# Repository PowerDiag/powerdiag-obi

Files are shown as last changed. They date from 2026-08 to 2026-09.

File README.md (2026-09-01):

# PowerDiag OBI — Interface Board

**PowerDiag OBI** is a dedicated hardware interface board (OBI V1.1, 2026.09.01) built around an
**Arduino Nano**, together with the firmware that drives it. It is a fork of
[Open Battery Information](https://github.com/mnh-jansson/open-battery-information).

On top of the original 1-Wire interface it adds an RGB status indicator, two front-panel buttons and
live battery voltage measurement, so the board can be used stand-alone as well as from the PC software.

> **Relation to the upstream project**
> The PC side is a browser app under `web/`, so there is nothing to install: open the page, pick the
> board, read the pack. It replaces the Python/Tkinter application, whose protocol handling it is a
> direct port of — the last Python version lives on in upstream's `v0.2.3` tag.
> For the original firmware documentation and project history see
> **https://github.com/mnh-jansson/open-battery-information**

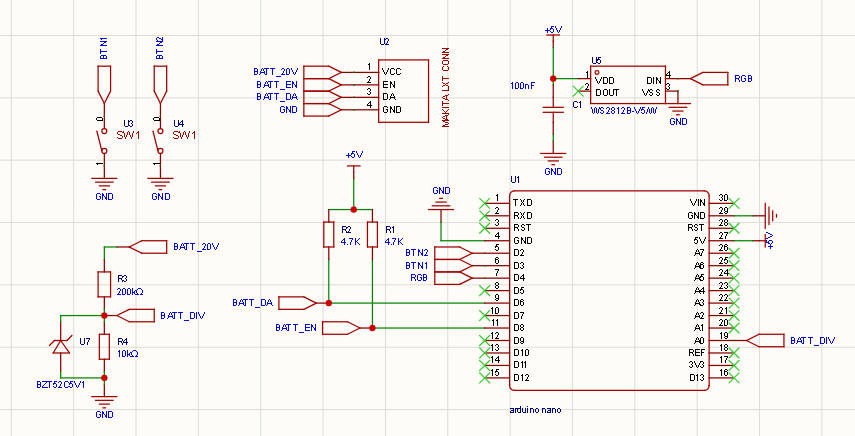
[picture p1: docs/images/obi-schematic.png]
schematic


---

## Features

### 1. WS2812 RGB status indicator (U5)

A single WS2812 in a 5050 package is used to show battery/tool state at a glance (idle, reading,
read OK, error, cleared, ...) without having to look at the PC.

* Data in (`DIN`) is driven from Arduino **D4**
* Powered from **+5V**, decoupled with **C1 (100 nF)**

### 2. Two push buttons (U3 / U4)

Both act on a hold, never on a stray press:

* **BTN1 → D3**, held **1 s** — read battery information. If the battery is already showing as
  locked, the same hold unlocks it (clears the error flags) and reads back the new state.
* **BTN2 → D2**, held **1 s** — dismiss the result and return the LED to dark. It shows nothing
  while held: the LED is answering whether the pack is locked, and blinking over that answer to
  report a button being pressed buried the one thing it is there for. Going dark at 1 s is the
  confirmation, and it needs the longer hold because there is nothing else to tell you it worked.

Both buttons switch the pin to **GND**, so they are active-low and are configured with
`INPUT_PULLUP` in firmware. No external pull-up resistors are fitted for the buttons.

### 3. Battery voltage measurement (ADC)

The pack voltage (`BATT_20V`) reaches **A0** through a resistor divider, and is sampled when the
PC asks for it:

* **R3 = 200 kΩ** (high side) / **R4 = 10 kΩ** (low side) → divider ratio **1:21**
* **U7 = BZT52C5V1** (5.1 V zener) clamps `BAT_DIV` to protect the ADC input

The ADC runs against the ATmega328P's **internal 1.1 V bandgap reference**, not against `AVCC`.
`AVCC` is only the USB rail minus a diode drop and moves with the port, the cable and the load,
while the bandgap does not move with the supply at all. `AREF` (U1 pin 18) is left unconnected on
the board, so nothing conflicts with it.

1.1 V across the 1:21 divider puts full scale at **23.1 V**, and a full 21 V pack at 91 % of the
range — the divider ratio is chosen for this reference:

| | Pack voltage | At A0 | ADC counts |
| --- | --- | --- | --- |
| Full scale | 23.1 V | 1.100 V | 1023 |
| Full 5S pack | 21.0 V | 1.000 V | 931 |
| Nominal 18 V pack | 18.0 V | 0.857 V | 798 |
| Resolution | **22.6 mV** | 1.07 mV | 1 |

Convert the raw reading back to pack voltage with:

```text
V_batt = (ADC / 1023) * 1.1 * 21 * VBAT_CALIBRATION
```

Anything above 23.1 V saturates the ADC and reads as 23.1 V rather than continuing to climb. That
is above a full LXT pack, and the zener still protects the input, but keep it in mind if you point
the board at a higher voltage source.

The measurement drives the idle colour of the status LED, and the PC application picks it up on
every read and shows it as **Terminal Voltage (measured)** next to the values the BMS reports.
It is fetched once per read, not polled.

**Load on the pack.** The divider is the only thing connected to `BATT_20V`, and it draws about
**100 µA** (21 V / 210 kΩ). The board can be left on a battery without meaningfully discharging it.

**What the zener is actually for.** In normal use U7 never conducts — a full pack only produces
1.0 V at A0, nowhere near the 5.1 V breakdown. It covers the fault case: if R4 goes open circuit
or is not fitted, A0 would otherwise see the full pack voltage, and U7 clamps it instead.

**Inserting a battery with the Nano unpowered is safe.** A0 sits about 0.6 V above the dead 5 V
rail, so the MCU's ESD clamp conducts, but R3 limits that current to the same ~100 µA — two orders
of magnitude below the ±1 mA injection limit. `BATT_20V` reaches nothing else on the board; the
Nano's `VIN` is not connected, the board is USB powered only.

#### Calibration

**The reading has to be calibrated per board.** The bandgap reference is stable against supply
changes, but its *absolute* value is only specified as **1.0 V to 1.2 V** — it is a per-chip
constant, so an uncalibrated board can read up to about 10 % off. Once trimmed it stays trimmed:
unlike an `AVCC` reference it does not need re-checking when you change USB port or cable.

Calibrate once, at compile time:

1. Insert a battery and measure its terminal voltage with a multimeter.
2. Read what the software reports as *Terminal Voltage (measured)*.
3. Set `VBAT_CALIBRATION` in [ArduinoOBI/src/main.cpp](ArduinoOBI/src/main.cpp) to
   `multimeter reading / reported reading`.
4. Rebuild and flash.

This is deliberately a compile-time constant — one number, set once per board. There is no runtime
calibration menu and nothing stored in EEPROM.

---

## Web app

The PC-side tool is a static web app in [`web/`](web/). It talks to the board over **Web Serial**, so
customers do not install anything — they open the page, pick the board once and read the pack.

    web/
      index.html            markup
      vendor/powerdiag.css  shared visual language (PowerDiag/powerdiag-ui)
      styles.css            what is specific to this tool
      icon.svg              app + tab icon
      manifest.webmanifest  PWA metadata, so it installs as a windowed app
      sw.js                 service worker, network first with an offline fallback
      js/transport.js       Web Serial framing (see the frame layout in ArduinoOBI/src/main.cpp)
      js/lxt.js             Makita LXT commands and parsing
      js/i18n.js            Japanese / English / Chinese strings
      js/app.js             UI

The shared stylesheet is vendored rather than linked from a shared URL, so the tool stays
self-contained and works offline and on `localhost`. Update it by copying a newer
`powerdiag.css` from [powerdiag-ui](https://github.com/PowerDiag/powerdiag-ui) and bumping `CACHE`
in `sw.js`.

**Before deploying,** stamp the build so the status bar names what the customer is running:

```
python tools/stamp-version.py
```

It writes `web/js/version.js` from whatever HEAD is at that moment, and marks the stamp with a `+`
if the working tree is dirty. Bump `CACHE` in `sw.js` in the same breath when assets changed.

**Deploying:** copy the contents of `web/` to `powerdiag.jp/obi`. Every path in the app is relative,
so it runs from any sub-path without a build step. It must be served over **HTTPS** — Web Serial is
unavailable on plain HTTP.

**Running it locally:** `python -m http.server` inside `web/`, then open `http://localhost:8000`.
`localhost` counts as a secure context, so the serial port works without a certificate.

**Serving it.** The app is served from our own server behind Cloudflare, and both layers have to
be told not to hold on to it. It is a few hundred KB, so caching buys nothing and only produces
customers running a build from weeks ago.

nginx:

```nginx
location /obi/ {
    alias /var/www/powerdiag/obi/;
    index index.html;

    # no-cache still allows 304s, so revalidating costs almost nothing.
    add_header Cache-Control "no-cache" always;
}

# Not in the stock mime.types. Without it the manifest is served as
# application/octet-stream and the app cannot be installed, while the page
# itself looks perfectly fine.
types {
    application/manifest+json  webmanifest;
}
```

Do not nest a `location` inside that block: an `add_header` in a child block drops every
`add_header` inherited from the parent.

On Cloudflare, add a Cache Rule matching URI Path starts with `/obi` set to **Bypass cache**, then
purge `https://powerdiag.jp/obi/*` once — the rule only affects later requests and does not evict
what is already at the edge.

Check both layers with:

```
curl -sI https://powerdiag.jp/obi/ | grep -iE "cache-control|cf-cache-status"
```

Expect `cache-control: no-cache` and `cf-cache-status: BYPASS`.

**Browser support:** desktop Chrome and Edge. Firefox and Safari do not implement Web Serial, and
neither does any mobile browser. Windows 10/11 ship with Edge, so customers need no extra download —
but the USB-serial driver (CH340 on most Nano boards) must be present, or the board simply will not
appear in the port picker.

---

## Battery connector (U2, Makita LXT)

| Pin | Net | Description |
| --- | --- | --- |
| 1 | `BATT_20V` | Pack positive, also fed to the divider  |
| 2 | `BAT_EN` | Enable line |
| 3 | `BAT_ONEWIRE` | 1-Wire data line |
| 4 | `GND` | Pack negative / ground |

`BAT_ONEWIRE` and `BAT_EN` are each pulled up to +5V with **4.7 kΩ** (R1 / R2).

## Pin assignment (Arduino Nano, U1)

| Arduino pin | Net | Function |
| --- | --- | --- |
| D2 | `BTN2` | Button 2 — dismiss result (active low, hold 1 s)  |
| D3 | `BTN1` | Button 1 — read / unlock (active low, hold 1 s) |
| D6 | `BAT_ONEWIRE` | 1-Wire data, 4.7 kΩ pull-up to +5V |
| D8 | `BAT_EN` | Battery enable, 4.7 kΩ pull-up to +5V |
| D4 | `DIN` | WS2812 data |
| A0 | `BAT_DIV` | Battery voltage via 200 k / 10 k divider |
| 5V / GND | — | Supply for WS2812 and pull-ups |

D6 and D8 keep the pin numbers used by the existing firmware (`ONEWIRE_PIN` / `ENABLE_PIN` in
`ArduinoOBI/src/main.cpp`), so the board is backwards compatible with the stock ArduinoOBI build and
the PC application keeps working unchanged.

Firmware support for the buttons, the WS2812 and the ADC is implemented in `ArduinoOBI` — see
[ArduinoOBI/README.md](ArduinoOBI/README.md#stand-alone-operation) for the LED colour codes.

---

## Board

| Layout | 3D |
| --- | -- |
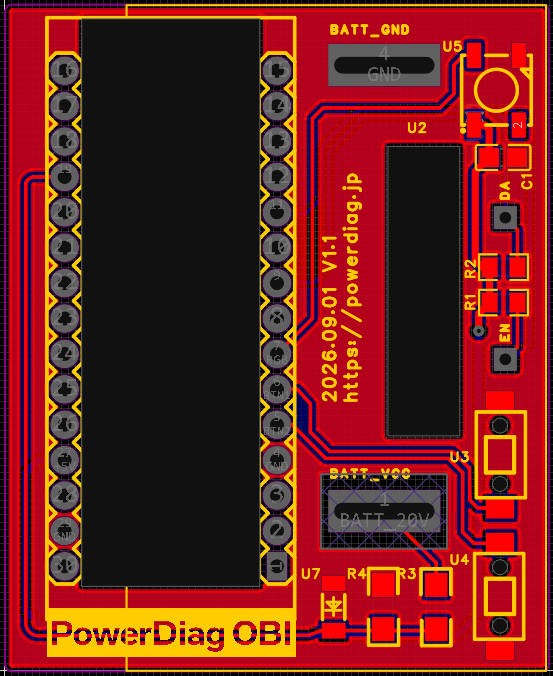
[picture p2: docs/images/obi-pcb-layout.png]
pcb layout
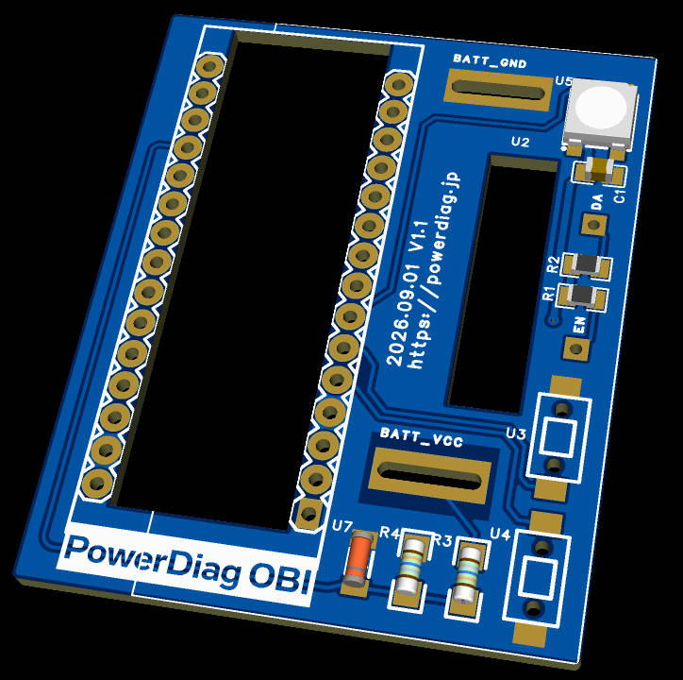
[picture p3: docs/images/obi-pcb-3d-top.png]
pcb top
|  |  |

Everything is on the top side. The Arduino Nano sits in a socket, with the buttons (U3/U4), the
WS2812 (U5), the battery terminals (`BAT_VCC` / `BAT_GND`, plus the `EN` and `DA` pads) and the
passives — R1, R2, R3, R4, the zener U7 and C1 — alongside it. Nothing is fitted to the bottom, so
the board sits flat and the case only has to clear one side.

## Getting the board

**Buy a kit** — the PCB together with all the components is available as a kit on AliExpress.
Search for **`open battery information`**
([search](https://www.aliexpress.com/wholesale?SearchText=open+battery+information)).

**Or build it yourself** — the full schematic and PCB are in
[obi-interface-board/](obi-interface-board/) as an **EasyEDA Pro 3.0** project (`ProDoc_OBI.epro2`).
Import it into [EasyEDA Pro](https://pro.easyeda.com/) and order the board straight from
[JLCPCB](https://jlcpcb.com/), or export Gerbers and have it made anywhere else. The SMD parts are
0603 and similar, all on the top side; the Nano, the connector and the switches are through-hole.
See [obi-interface-board/README.md](obi-interface-board/README.md).

## Enclosure

A two-part printable case is in [`case/`](case/), as STLs and as the Fusion 360 sources they were
made from — the sources are there so you can move a cutout rather than start over.

---

## Credits & license

This project builds on [Open Battery Information](https://github.com/mnh-jansson/open-battery-information)
by [mnh-jansson](https://github.com/mnh-jansson). The firmware is derived from that work, and the
protocol handling in `web/js/lxt.js` is a port of its `makita_lxt.py`; see the upstream repository for
the original README, documentation and project history.

The bundled 1-Wire library in `ArduinoOBI/lib/OneWire` is by Jim Studt, Paul Stoffregen and other
contributors, under the license stated in its own source headers.

Everything is MIT licensed — see [LICENSE.md](LICENSE.md), which carries both the original copyright
and ours.

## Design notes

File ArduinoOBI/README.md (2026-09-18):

# ArduinoOBI

## Hardware

This simple interface can be built using an Arduino Nano and some external resistors.

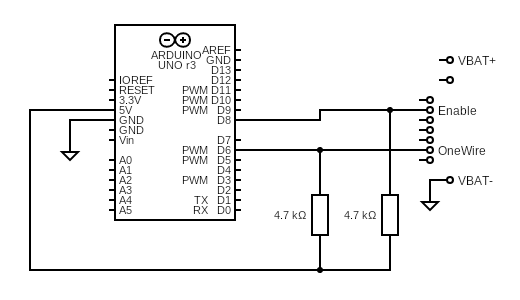
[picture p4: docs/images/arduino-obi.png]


For the interface board of this fork (Arduino Nano, WS2812 status LED, two buttons and pack voltage
measurement) see the [main README](../README.md#hardware-obi-interface-board).

---

## Firmware versions

Two firmwares run on this board, and the web app supports both. Which one is on it is visible from
the version the board reports on connect (interface command `0x01`):

| Version | Firmware | Commands | Board features |
| --- | --- | --- | --- |
| `0.x.x` (stock is `0.2.1`) | upstream ArduinoOBI, unmodified | `0x01`, `0x31`, `0x33`, `0xCC` | serial bridge only — LED and buttons dark |
| `9.x.x` | this repo (PowerDiag) | the above plus `0x02`, `0x36` | status LED, buttons, pack voltage |

The `9` is deliberate: upstream numbers itself `0.x.x`, so nothing it releases can ever be mistaken
for this firmware or the other way round. Set in `src/main.cpp`.

The web app reads the version once on connect and picks its read path from it. On stock firmware it
sends only stock commands and behaves exactly as upstream does — notably F0513 cell voltages, which
it reads one register per command because the atomic read (`0x36`) is not there. It says nothing
about the firmware being stock; a board doing what it was built to do is not a fault. The `0.3.x`
builds that predate this scheme report as stock and should be reflashed.

---

## Building and releasing

Built on the PowerDiag server, where PlatformIO is installed (pipx; `pio` lives in
`~/.local/bin`) and the AVR toolchain is already fetched. The walkthrough further down is
upstream's VS Code route and still works, but the short version is:

```sh
cd ~/powerdiag-obi/ArduinoOBI
pio run -e nano          # -> .pio/build/nano/firmware.hex
```

The build is released through the web flasher at `https://powerdiag.jp/flash/`, which serves
this firmware and the stock one side by side. Copy the hex into `powerdiag-site` at
`public/flash/firmware/powerdiag-obi.hex` and update `public/flash/firmware/index.json`:

- `version` — must match `ARDUINO_OBI_VERSION_*` in `src/main.cpp`. The OBI app picks its read
  path from this number, so getting it wrong makes the app treat the board as stock.
- `bytes` — the **program** size, not the file size: the sum of the data lengths of the hex's
  type `00` records, which is the figure `pio run` prints as `Flash: ... used N bytes`.

Then deploy `powerdiag-site` as usual. `Flash-Nano.ps1` and the web flasher both query the
version after writing, so a mismatch shows up immediately on the next flash.

---

## Stand-alone operation

The board can be used without the PC application. The battery-facing commands are exactly the
frames the PC application sends, so a local read behaves identically to a read from the software.

### Buttons

Both buttons act on a **1 second hold** (`BTN_HOLD_MS`), not on a plain press, so a bumped button
never talks to the battery. The LED blinks while a button is held; releasing early cancels.

| Button | Pin | Hold | Action |
| --- | --- | ---- | --- |
| BTN1 (U4) | D3 | 1 s | Read the battery message and latch the result on the LED |
| BTN1 (U4) | D3 | 1 s | **While red/green is alternating:** unlock the BMS, then read back |
| BTN2 (U3) | D2 | 1 s | Dismiss the latched result, back to the idle voltage display |

The unlock path is the same two frames the PC application sends for *Clear errors*: test mode
(`D9 96 A5`) followed by reset error (`DA 04`). It only runs from the locked state, so the write to
the BMS cannot happen unless the board has actually read a locked battery first.

### Status LED (WS2812 on D4)

| Colour | Pattern | Meaning |
| --- | --- | --- |
| Red, green, blue | once at power-up | Firmware started, and all three channels work |
| Dark | — | Idle. The LED speaks only about the last read |
| Blue | blink | BTN1 held, and talking to the battery |
| **Green** | **solid** | **Read OK — BMS is unlocked** |
| **Red / green** | **alternating** | **Read OK — BMS is LOCKED**, hold BTN1 again to unlock |
| Magenta | blink, 2 s | No usable answer (all `0x00` / all `0xFF`) — check the pack is seated |
| Cyan | blink, brief | Unlock done, reading back |

The lock state stays up until BTN2 dismisses it or another read replaces it: it is the answer, and an
answer that erases itself is no use to someone who looked away. Everything else is transient and the
LED returns to dark.

**BTN2 shows nothing while held.** It dismisses the latched result after a **1 s** hold, and the LED
going dark is the confirmation. It used to blink white from the moment it was pressed, which painted
over the lock state — the one thing the LED is there for — to report a button being pressed.

The LED does not show the pack voltage. It did, as a red-to-green gradient, and that made green mean
two unrelated things — a full pack, and an unlocked one — told apart only by whether a result
happened to be latched, which nobody can see. The voltage is on the PC to three decimal places; the
lock state is the only thing this board can tell you on its own.

Results are **latched**: they stay on the LED until BTN2 dismisses them or another read replaces
them. Only then does the LED return to the idle voltage indication. Brightness is set by
`STATUS_LED_BRIGHTNESS`.

The firmware prints nothing extra on the serial port, so the PC application protocol is unaffected
by local button use.

---

## Pack voltage over USB

Interface command **`0x02`** returns the voltage measured on the battery terminals, so the PC
application can display it without a battery data read:

```text
request : 01 00 02 02
response: 02 02 <millivolts, little endian>
```

The PC application requests it once per read and shows it as *Terminal Voltage (measured)*.
Stock firmware has no such command and is never asked for it; a board on this firmware but without
the divider fitted fails the request once and is not asked again. Either way the field is simply
left empty.

The reading is referenced to the ATmega328P's internal 1.1 V bandgap, whose absolute value is only
specified as 1.0–1.2 V, so set `VBAT_CALIBRATION` in `src/main.cpp` once per board before relying on
the value. Full scale is 23.1 V. See [Calibration](../README.md#calibration) in the main README.

---

## Prerequisites

Ensure you have the following installed on your system:

1. **VS Code (Visual Studio Code)**  
   Download from [here](https://code.visualstudio.com/).

2. **PlatformIO Extension for VS Code**  
   Install the PlatformIO extension from the Extensions Marketplace in VS Code.

3. **Git (OPTIONAL)**  

4. **Arduino Nano**  
   Ensure you have a working Arduino Nano board and a USB cable to connect it to your computer.
   Build the circuit according to the schematic.

---

## Step 1: Clone the ArduinoOBI Repository

1. Open your terminal.
2. Clone the repository using the command:

   ```bash
   git clone https://github.com/mnh-jansson/open-battery-information.git
   ```

Or,

1. Download the repository as a .ZIP file.
---

## Step 2: Open the Project in VS Code

  Open VS Code.
  Go to File > Open Folder and select the ArduinoOBI project folder.
  PlatformIO will automatically detect the project. If not, ensure the folder contains a platformio.ini file.

## Step 3: Compile the Project

  Open the PlatformIO sidebar by clicking on the PlatformIO icon in the VS Code activity bar.
  Click on the "Project Tasks" dropdown for nano.
  Under "General", click Build to compile the code.
  Check the output terminal for any errors. A successful build will show a "Success" message.

## Step 4: Flash the Code to the Arduino Nano

  Connect your Arduino Nano to your computer using a USB cable.
  In the PlatformIO sidebar, go to the "Project Tasks" dropdown for nano.
  Under "General", click Upload.
  PlatformIO will detect the correct port and upload the firmware to your Arduino Nano.
  A successful upload will display an "Upload complete" message in the terminal.

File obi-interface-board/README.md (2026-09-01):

# OBI Interface Board — design files

`ProDoc_OBI.epro2` is the complete schematic and PCB of the OBI interface board, exported from
**EasyEDA Pro 3.0**. It contains everything shown in the [main README](../README.md#hardware-obi-interface-board):
the Arduino Nano carrier, the Makita LXT connector, the two buttons, the WS2812 status LED and the
pack voltage divider.

## Opening it

Open [EasyEDA Pro](https://pro.easyeda.com/) (version 3.0 or newer) and use
**File → Import → EasyEDA Pro (`.epro2`)**. The standard edition of EasyEDA cannot open this format.

## Buying a kit

If you would rather not order a PCB and source the parts separately, the board and all its
components are sold as a kit on AliExpress — search for **`open battery information`**
([search](https://www.aliexpress.com/wholesale?SearchText=open+battery+information)).

## Building your own

The project is set up so you can have the board made directly:

1. Import the `.epro2` into EasyEDA Pro.
2. Order it from **[JLCPCB](https://jlcpcb.com/)** straight from the editor, or export Gerbers and
   use any other manufacturer.
3. The BOM is an Arduino Nano, a Makita LXT connector, one WS2812 in a 5050 package, two tactile
   switches, four resistors, one zener and one 100 nF capacitor. The Nano, the connector and the
   switches are through-hole; the rest are 0603-and-similar SMD parts, all on the top side. See the
   pin and component tables in the main README.

Feel free to copy, modify or re-spin the board.

## Enclosure

STLs for a printable two-part case are in [`../case/`](../case/).

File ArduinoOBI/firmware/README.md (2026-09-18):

# ArduinoOBI prebuilt firmware

Prebuilt firmware images, kept so an old build can be flashed back without
reconstructing a toolchain.

| Version | Source | Notes |
|---|---|---|
| [upstream-0.2.1](upstream-0.2.1/) | upstream `1a24a38`, unmodified | Stock ArduinoOBI. Serial bridge only — no LED, buttons or voltage sensing. |

This repo's own firmware is built from `src/` and numbers itself `9.x.x`, which is how the web app
tells the two apart; see [Firmware versions](../README.md#firmware-versions).

Flash with `ArduinoOBI/tools/Flash-Nano.ps1`; each folder has its own `FLASH.md`.

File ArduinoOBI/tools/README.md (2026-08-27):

# Flash-Nano.ps1 — batch flasher for OBI Nano clones

Flashes the ArduinoOBI firmware onto the Arduino Nano clones used by this project
(both the **FTDI** and **CH340** variants). Written for flashing many boards in a row.

## Why not just use `pio run -t upload` / avrdude?

These clones' **auto-reset does not work** with avrdude/PlatformIO — avrdude pulses the
reset line once at the start, the optiboot window is only ~1 s, and the clones' DTR wiring
doesn't cooperate. Result: `avrdude: stk500_getsync(): not in sync` at every baud, forever.

This script talks the **STK500v1** protocol directly and **pulses DTR+RTS itself** to enter
the bootloader, so no button pressing and no timing luck required. It also **verifies** the
flash by reading every page back, then confirms the firmware boots by querying its version.

## Requirements

- Windows PowerShell (the built-in `powershell.exe` is fine).
- The compiled firmware at `..\.pio\build\nano\firmware.hex`.
  Build/refresh it with: `pio run -e nano`  (run from the `ArduinoOBI` folder).
- The board's USB-serial driver installed (FTDI or CH340). No PlatformIO needed at flash time.

## Usage

Run from this `tools` folder.

### One board
```powershell
.\Flash-Nano.ps1
```
Auto-detects the connected adapter (FTDI / CH340 / CP210x / genuine Arduino) and flashes it.
Exit code `0` = success, `1` = failure (handy for scripting).

### Many boards — LOOP MODE (recommended for the 100-board run)
```powershell
.\Flash-Nano.ps1 -Loop
```
Then just: **plug a board → it flashes & verifies → unplug it → plug the next → repeat.**
It prints a running `total OK / failed` tally. `Ctrl+C` to stop.

> Plug in **one board at a time**. If two adapters are connected it pauses and asks you to
> get down to one, so it never flashes the wrong device.

### Useful options
| Option | Default | Purpose |
|---|---|---|
| `-Port COMx` | auto-detect | Force a specific port (skip auto-detect). |
| `-Hex <path>` | `..\.pio\build\nano\firmware.hex`| Flash a different hex file. |
| `-BootBaud` | `115200,57600` | Bootloader sync bauds to try, in order. |
| `-AppBaud` | `9600` | OBI firmware serial baud, for the post-flash check.|
| `-NoVerifyRun` | off | Skip the version query (read-back verify still runs). |

## What a good run looks like
```
Firmware: firmware.hex  (3368 bytes, 27 pages)

[COM10] flashing...
  synced @ 115200 baud
[COM10] OK - firmware running, version 0.2.1
```

## Troubleshooting

- **`No FTDI serial port found`** — board not plugged in, or driver missing. Plug it in / install
  the CH340 or FTDI driver, then re-run. `-Loop` will simply wait until a board appears.
- **`Multiple FTDI ports found`** — more than one adapter is connected. Unplug the others, or
  pass `-Port COMx`. In `-Loop` mode, keep to one board at a time.
- **Port number changes between boards (e.g. COM12 → COM10)** — normal; some counterfeit-FTDI
  clones re-enumerate on a new COM number after resets. Auto-detect handles it; that's why you
  should prefer auto-detect over `-Port` for the batch run.
- **`Could not enter bootloader`** — usually the board was unplugged mid-flash, or a dead/erased
  bootloader. Re-seat the USB cable and retry. If a specific board never syncs, its bootloader may
  be gone (needs an ISP programmer to restore) — set it aside.
- **`Firmware not found`** — build it: `pio run -e nano` from the `ArduinoOBI` folder.

## Notes

- Bootloader is optiboot @ **115200** on these boards (the script also tries 57600 as a fallback).
- After flashing, the OBI firmware runs its serial protocol at **9600 baud** — that's what the
  OBI GUI (and the script's post-flash check) uses, not the bootloader baud.
- Flash page size is 128 bytes (atmega328p). The read-back verify compares every byte.

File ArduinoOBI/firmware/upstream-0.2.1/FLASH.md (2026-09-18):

# ArduinoOBI upstream firmware — v0.2.1

The **unmodified upstream** ArduinoOBI firmware, kept here so a board can always
be put back to stock: to reproduce a bug against the original, to check whether
behaviour we changed was already there, or to hand someone a board running the
same code as the upstream project.

## Provenance

Built from [mnh-jansson/open-battery-information](https://github.com/mnh-jansson/open-battery-information)
at commit `1a24a38`, PlatformIO `nano` env, unmodified sources.

* `ArduinoOBI-upstream-v0.2.1.hex` — 3368 bytes, 27 flash pages
* SHA256 `a499e89e9b548c81de451573d9744090d39b7b43f7e2322d04b1695fdc1832fd`

Reports **0.2.1** over the serial version command, which is how you tell it apart
from this repo's firmware (`9.x.x`) at a glance — and how the web app tells, too.

## Flashing

```powershell
cd ArduinoOBI/tools
.\Flash-Nano.ps1 -Hex ../firmware/upstream-0.2.1/ArduinoOBI-upstream-v0.2.1.hex
```

Use the script rather than `pio run -t upload` or plain avrdude: on the FTDI and
CH340 Nano clones this project uses, the auto-reset does not cooperate with
avrdude — it pulses reset once, the optiboot window is about a second, and you
get `stk500_getsync(): not in sync` at every baud, forever. The script speaks
STK500v1 and pulses DTR+RTS itself, reads every page back to verify, then
confirms the firmware booted by querying its version.

A good run ends with:

```
[COM12] OK - firmware running, version 0.2.1
```

## Differences from this repo's firmware

Upstream is the serial bridge only — the PC application drives everything. It
has no support for the interface board's additions: no WS2812 status LED, no
buttons, no pack voltage sensing. Flashing it onto an assembled board leaves the
LED dark and the buttons dead; that is expected, not a fault.

The battery-facing 1-Wire code in this repo is deliberately unchanged from
upstream, so reads behave identically either way — with one addition, command
`0x36`, which runs a priming-and-retry sequence F0513 packs need before they
give up their cell registers. Upstream has no such command, so on this firmware
the web app falls back to reading those registers one at a time, as upstream
does. Every other read is the same on both.

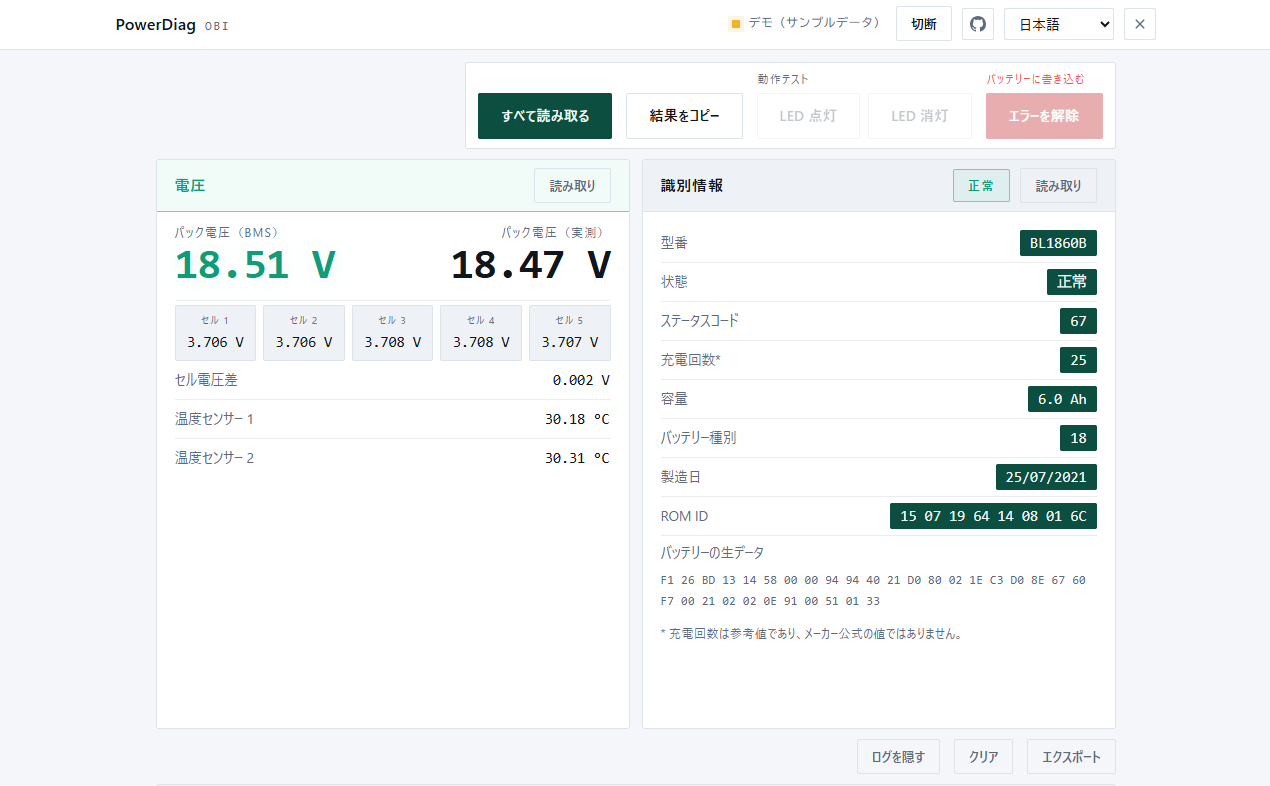
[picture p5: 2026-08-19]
web/screenshots/dashboard.png

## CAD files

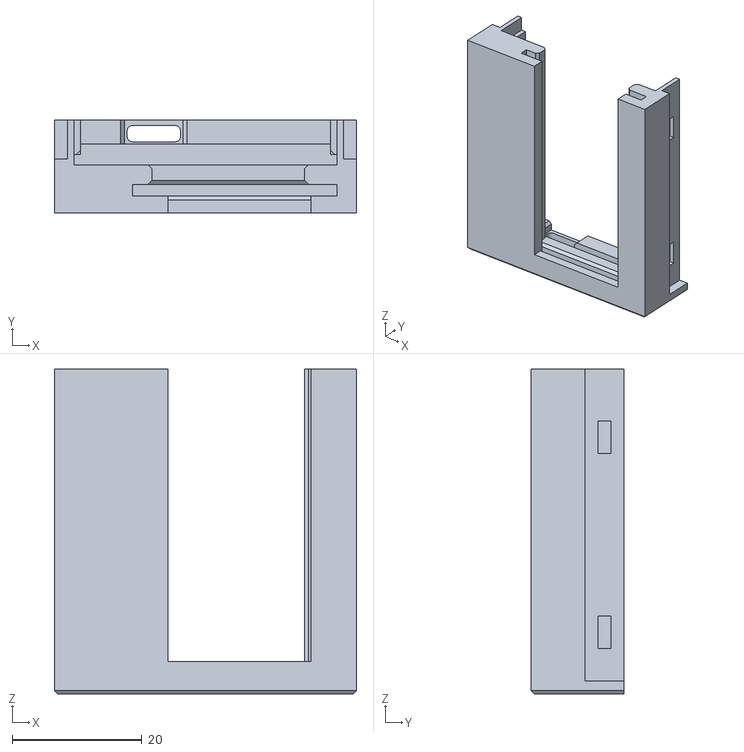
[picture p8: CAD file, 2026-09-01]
case/POWERDIAG_OBI_CASE_1.stl
46.5 x 14.3 x 50.0

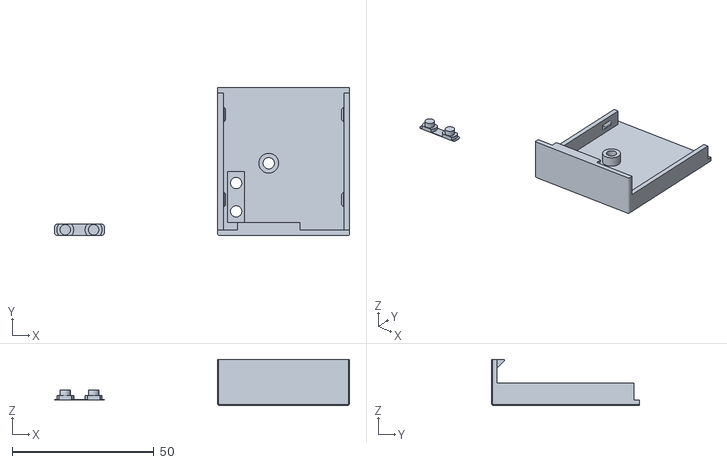
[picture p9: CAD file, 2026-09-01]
case/POWERDIAG_OBI_CASE_2.stl
104.1 x 52.2 x 16.3

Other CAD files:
case/POWERDIAG_OBI_CASE_1.f3d
case/POWERDIAG_OBI_CASE_2.f3d

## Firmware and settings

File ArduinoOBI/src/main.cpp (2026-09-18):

#include <Arduino.h>
#include <Adafruit_NeoPixel.h>
#include "OneWire2.h"

/* Version 9.x.x marks this as PowerDiag's firmware, not upstream ArduinoOBI.
 * Upstream numbers itself 0.x.x (stock is 0.2.1), so starting at 9.0.0 leaves
 * no room for a collision and makes the board self-identifying: the web app
 * asks for the version on connect and uses the extra commands this firmware
 * adds — 0x02 (pack voltage) and 0x36 (atomic F0513 cell read) — only when the
 * major is 9 or above. On anything else it sticks to the stock command set.
 * The 0.3.x builds that came before this scheme count as stock; reflash them. */
/** Major version number (X.x.x) */
#define ARDUINO_OBI_VERSION_MAJOR 9
/** Minor version number (x.X.x) */
#define ARDUINO_OBI_VERSION_MINOR 0
/** Patch version number (x.x.X) */
#define ARDUINO_OBI_VERSION_PATCH 0

#define ONEWIRE_PIN 6
#define ENABLE_PIN 8
/** U5, WS2812 DIN */
#define STATUS_LED_PIN 4
/** U4, BTN1 - read battery information */
#define BTN_READ_PIN 3
/** U3, BTN2 - dismiss the latched read result */
#define BTN_CLEAR_PIN 2
/** BAT_DIV, pack voltage through the R10/R11 divider */
#define VBAT_ADC_PIN A0
#define ADC_MAX_COUNTS 1023.0f
/* Internal 1.1V bandgap, selected in setup(). Not AVCC: the 5V rail is only
 * USB VBUS minus a diode drop and moves with the port, the cable and the load.
 * 1.1V across the 1:21 divider gives a 23.1V full scale. */
#define ADC_REF_VOLTS 1.1f

/** Divider ratio of R10 (200k) / R11 (10k) */
#define VBAT_DIVIDER 21.0f
/**
 * Per board trim. The bandgap reference is stable, but its absolute value is
 * only specified as 1.0V to 1.2V, so it differs from chip to chip. Set this to
 * (multimeter reading / reported reading) once, see the README.
 */
#define VBAT_CALIBRATION 1.000f
/** Below this the pack is considered absent */
/** Pack voltage mapped to the "empty" indicator colour */
/** Pack voltage mapped to the "full" indicator colour */
/** Interval between idle voltage measurements */

/** How long a failed read complains before the LED goes dark */
#define RESULT_FAIL_MS 2000

#define BTN_DEBOUNCE_MS 25
/** Both buttons act on a hold, not on a plain press */
#define BTN_HOLD_MS 1000
/** Dismiss only touches the display, so this is just anti-fumble, not a guard */
#define BTN_CLEAR_HOLD_MS 1000
/** Global scaling of the WS2812, 0-255 */
#define STATUS_LED_BRIGHTNESS 48

/* Local button commands. These are the exact same frames the PC application
 * sends (see OpenBatteryInformation/modules/makita_lxt.py):
 *   READ_MSG_CMD    = [0x01, 0x02, 0x28, 0x33, 0xAA, 0x00]
 *   TESTMODE_CMD    = [0x01, 0x03, 0x09, 0x33, 0xD9, 0x96, 0xA5]
 *   RESET_ERROR_CMD = [0x01, 0x02, 0x09, 0x33, 0xDA, 0x04]
 * i.e. command 0x33, the payload below and the response length below. */
static byte READ_MSG_DATA[] = {0xAA, 0x00};
#define READ_MSG_RSP_LEN 0x28
static byte TESTMODE_DATA[] = {0xD9, 0x96, 0xA5};
#define TESTMODE_RSP_LEN 0x09
static byte RESET_ERROR_DATA[] = {0xDA, 0x04};
#define RESET_ERROR_RSP_LEN 0x09

/* Offsets into the response payload. The PC application indexes the framed
 * response (response[0] = cmd, response[1] = length), so payload[i] here is
 * response[i + 2] there. */
#define OFFSET_STATUS_CODE 27
#define OFFSET_LOCK 28

OneWire makita(ONEWIRE_PIN);
Adafruit_NeoPixel status_led(1, STATUS_LED_PIN, NEO_GRB + NEO_KHZ800);

#define RGB(r, g, b) (((uint32_t)(r) << 16) | ((uint32_t)(g) << 8) | (uint32_t)(b))

#define COLOR_OFF RGB(0, 0, 0)
/** BTN1 held, and talking to the battery */
#define COLOR_BUSY RGB(0, 0, 255)
/** BMS is unlocked */
#define COLOR_OK RGB(0, 255, 0)
/** BMS is locked, alternated with COLOR_OK */
#define COLOR_LOCKED RGB(255, 0, 0)
/** No usable answer from the battery */
#define COLOR_FAIL RGB(255, 0, 255)
/** Unlock done */
#define COLOR_CLEARED RGB(0, 255, 255)

enum LedMode {
	LED_SOLID,
	LED_BLINK,
	LED_BREATHE,
	/** Alternates between led_color and led_color_b */
	LED_ALTERNATE,
};

static bool led_off_at_expiry = false;
static uint32_t led_color = COLOR_OFF;
static uint32_t led_color_b = COLOR_OFF;
static uint8_t led_mode = LED_SOLID;
static uint16_t led_period = 0;
/** millis() at which the current pattern expires, 0 = stays until replaced */
static uint32_t led_expiry = 0;
static uint32_t led_written = 0xFFFFFFFF;

struct Button {
	uint8_t pin;
	bool raw;
	bool state;
	uint32_t t_raw;
	uint32_t t_pressed;
};

/** Result of the last local read, latched on the LED until it is dismissed */
enum ObiResult {
	RESULT_NONE,
	RESULT_UNLOCKED,
	RESULT_LOCKED,
	RESULT_FAIL,
};

static Button btn_read;
static Button btn_clear;
static bool read_armed = false;
static bool clear_armed = false;
static uint8_t last_result = RESULT_NONE;

void cmd_and_read_33(byte *cmd, uint8_t cmd_len, byte *rsp, uint8_t rsp_len) {
	int i;
	makita.reset();
	delayMicroseconds(400);
	makita.write(0x33,0);

	for (i=0; i < 8; i++) {
		delayMicroseconds(90);
		rsp[i] = makita.read();
	}

	for (i=0; i < cmd_len; i++) {
		delayMicroseconds(90);
		makita.write(cmd[i],0);
	}

	for (i=8; i < rsp_len + 8; i++) {
		delayMicroseconds(90);
		rsp[i] = makita.read();
	}
}

void cmd_and_read_cc(byte *cmd, uint8_t cmd_len, byte *rsp, uint8_t rsp_len) {
	int i;
	makita.reset();
	delayMicroseconds(400);
	makita.write(0xcc,0);

	for (i=0; i < cmd_len; i++) {
		delayMicroseconds(90);
		makita.write(cmd[i],0);
	}

	for (i=0; i < rsp_len; i++) {
		delayMicroseconds(90);
		rsp[i] = makita.read();
	}
}

void cmd_and_read(byte *cmd, uint8_t cmd_len, byte *rsp, uint8_t rsp_len) {
	int i;
	makita.reset();
	delayMicroseconds(400);

	for (i=0; i < cmd_len; i++) {
		delayMicroseconds(90);
		makita.write(cmd[i],0);
	}

	for (i=0; i < rsp_len; i++) {
		delayMicroseconds(90);
		rsp[i] = makita.read();
	}
}

/* --- Status LED (U5) ------------------------------------------------------ */

/**
 * Select the pattern shown on the WS2812.
 *
 * @param color     Base colour, full intensity.
 * @param mode      LED_SOLID, LED_BLINK or LED_BREATHE.
 * @param period_ms Cycle time for the blink/breathe modes.
 * @param hold_ms   Time before the pattern expires, 0 to keep it indefinitely.
 */
void led_set(uint32_t color, uint8_t mode, uint16_t period_ms, uint16_t hold_ms) {
	led_off_at_expiry = false;
	led_color = color;
	led_color_b = color;
	led_mode = mode;
	led_period = period_ms ? period_ms : 1000;
	led_expiry = hold_ms ? millis() + hold_ms : 0;
}

/**
 * A pattern that says its piece and stops. Without this an expired hold keeps
 * animating — expiry only ends led_holding(), it never touched the pixel — so
 * anything not replaced by a later led_set() blinked until the board was
 * unplugged.
 */
void led_set_transient(uint32_t color, uint8_t mode, uint16_t period_ms, uint16_t hold_ms) {
	led_set(color, mode, period_ms, hold_ms);
	led_off_at_expiry = true;
}

/** Alternate between two colours, half the period each. */
void led_set_alternate(uint32_t color_a, uint32_t color_b, uint16_t period_ms, uint16_t hold_ms) {
	led_set(color_a, LED_ALTERNATE, period_ms, hold_ms);
	led_color_b = color_b;
}

bool led_holding() {
	return led_expiry != 0 && (int32_t)(millis() - led_expiry) < 0;
}

/** Drive the WS2812 from the current pattern. Non-blocking, call often. */
void led_update() {
	uint32_t now = millis();

	if (led_off_at_expiry && !led_holding()) {
		led_set(COLOR_OFF, LED_SOLID, 0, 0);
	}

	uint32_t base = led_color;
	uint16_t level = 255;

	if (led_mode == LED_BLINK) {
		level = ((now % led_period) < (uint32_t)(led_period / 2)) ? 255 : 0;
	}
	else if (led_mode == LED_BREATHE) {
		uint16_t half = led_period / 2;
		uint16_t phase = now % led_period;
		level = (phase < half) ? (phase * 255UL / half) : ((led_period - phase) * 255UL / half);
	}
	else if (led_mode == LED_ALTERNATE) {
		base = ((now % led_period) < (uint32_t)(led_period / 2)) ? led_color : led_color_b;
	}

	uint16_t scale = level * STATUS_LED_BRIGHTNESS / 255;
	uint8_t r = (uint16_t)((base >> 16) & 0xFF) * scale / 255;
	uint8_t g = (uint16_t)((base >> 8) & 0xFF) * scale / 255;
	uint8_t b = (uint16_t)(base & 0xFF) * scale / 255;
	uint32_t out = RGB(r, g, b);

	if (out != led_written) {
		status_led.setPixelColor(0, out);
		status_led.show();
		led_written = out;
	}
}

/** Block until the current pattern expires, keeping the LED animated. */
void led_wait() {
	while (led_holding()) {
		led_update();
	}
}

/* --- Pack voltage (A0 / BAT_DIV) ------------------------------------------ */

float read_pack_voltage() {
	uint16_t acc = 0;

	for (uint8_t i = 0; i < 8; i++) {
		acc += analogRead(VBAT_ADC_PIN);
	}

	return (acc / 8.0f) * (ADC_REF_VOLTS / ADC_MAX_COUNTS) * VBAT_DIVIDER * VBAT_CALIBRATION;
}

/* --- Indication ----------------------------------------------------------- */

/**
 * Red, green, blue at power-up. It says the firmware started, and it says the
 * three channels of the WS2812 all work — a dead channel would otherwise show
 * up much later as an idle colour that reads wrong, which is a hard fault to
 * even notice, let alone diagnose.
 */
void led_selftest() {
	static const uint32_t SEQUENCE[] = { RGB(255, 0, 0), RGB(0, 255, 0), RGB(0, 0, 255) };

	for (uint8_t i = 0; i < 3; i++) {
		led_set(SEQUENCE[i], LED_SOLID, 0, 220);
		led_wait();
	}
	/* A full second dark, so the self-test reads as finished before the idle
	 * colour arrives. Any shorter and the last blue runs straight into it. */
	led_set(COLOR_OFF, LED_SOLID, 0, 1000);
	led_wait();
}

/**
 * Idle: dark. The LED says one thing now — whether the last read found the
 * pack locked — and it said two before. Green meant a full pack and it also
 * meant an unlocked one, told apart only by whether a result happened to be
 * latched, which is not something anyone can see. The voltage is on the PC to
 * three decimal places; the lock state is the only thing the board alone can
 * tell you.
 */
void show_idle() {
	led_set(COLOR_OFF, LED_SOLID, 0, 0);
}

/**
 * Show the latched result of the last read. The lock state stays up until BTN2
 * dismisses it or another read replaces it — it is the answer, and an answer
 * that erases itself is no use to someone who looked away. A failed read is
 * not an answer, so it says so for 3 s and gets out of the way.
 */
void show_result() {
	switch (last_result) {
		case RESULT_UNLOCKED:
			led_set(COLOR_OK, LED_SOLID, 0, 0);
			break;
		case RESULT_LOCKED:
			led_set_alternate(COLOR_LOCKED, COLOR_OK, 500, 0);
			break;
		case RESULT_FAIL:
			led_set_transient(COLOR_FAIL, LED_BLINK, 150, RESULT_FAIL_MS);
			break;
		default:
			show_idle();
			break;
	}
}

/* --- Buttons (U3 / U4) ---------------------------------------------------- */

void button_init(Button *b, uint8_t pin) {
	/* U3/U4 switch the pin to GND, there are no external pull-ups fitted. */
	pinMode(pin, INPUT_PULLUP);
	b->pin = pin;
	b->raw = false;
	b->state = false;
	b->t_raw = 0;
	b->t_pressed = 0;
}

/**
 * Debounce one button.
 *
 * @param pressed  Set when the button just went down.
 * @param released Set when the button just came up.
 */
void button_update(Button *b, bool *pressed, bool *released) {
	bool raw = (digitalRead(b->pin) == LOW);
	uint32_t now = millis();

	*pressed = false;
	*released = false;

	if (raw != b->raw) {
		b->raw = raw;
		b->t_raw = now;
		return;
	}

	if ((now - b->t_raw) < BTN_DEBOUNCE_MS || raw == b->state) {
		return;
	}

	b->state = raw;

	if (raw) {
		b->t_pressed = now;
		*pressed = true;
	}
	else {
		*released = true;
	}
}

/* --- Local (button driven) battery access --------------------------------- */

/* The transactions below deliberately use the same primitives, the same enable
 * line handling and the same delays as read_usb(), so a local read behaves
 * exactly like the same command coming from the PC application. */

/** BTN1 held: read the battery message and latch the lock state on the LED. */
void local_read() {
	byte payload[8 + READ_MSG_RSP_LEN];
	bool all_ff = true;
	bool all_00 = true;

	led_set(COLOR_BUSY, LED_BLINK, 160, 0);
	led_update();

	digitalWrite(ENABLE_PIN, HIGH);
	delay(400);
	cmd_and_read_33(READ_MSG_DATA, sizeof(READ_MSG_DATA), payload, READ_MSG_RSP_LEN);
	digitalWrite(ENABLE_PIN, LOW);

	for (uint8_t i = 0; i < READ_MSG_RSP_LEN; i++) {
		if (payload[i] != 0xFF) {
			all_ff = false;
		}
		if (payload[i] != 0x00) {
			all_00 = false;
		}
	}

	if (all_ff || all_00) {
		/* Same rule the PC application uses to reject a response. */
		last_result = RESULT_FAIL;
	}
	else if (payload[OFFSET_LOCK] & 0x0F) {
		last_result = RESULT_LOCKED;
	}
	else {
		last_result = RESULT_UNLOCKED;
	}

	show_result();
}

/**
 * BTN1 held while the locked pattern is shown: enter test mode, clear the
 * errors, then read the battery again so the LED shows the new state.
 */
void local_unlock() {
	byte payload[8 + TESTMODE_RSP_LEN];

	led_set(COLOR_BUSY, LED_BLINK, 80, 0);
	led_update();

	digitalWrite(ENABLE_PIN, HIGH);
	delay(400);
	cmd_and_read_33(TESTMODE_DATA, sizeof(TESTMODE_DATA), payload, TESTMODE_RSP_LEN);
	digitalWrite(ENABLE_PIN, LOW);

	digitalWrite(ENABLE_PIN, HIGH);
	delay(400);
	cmd_and_read_33(RESET_ERROR_DATA, sizeof(RESET_ERROR_DATA), payload, RESET_ERROR_RSP_LEN);
	digitalWrite(ENABLE_PIN, LOW);

	led_set_transient(COLOR_CLEARED, LED_BLINK, 120, 600);
	led_wait();

	/* Show what the battery reports now that the errors have been cleared. */
	local_read();
}

void handle_buttons() {
	bool pressed;
	bool released;

	button_update(&btn_read, &pressed, &released);
	if (pressed) {
		read_armed = true;
		led_set(COLOR_BUSY, LED_BLINK, 250, 0);
	}
	if (read_armed && btn_read.state && (millis() - btn_read.t_pressed) >= BTN_HOLD_MS) {
		read_armed = false;
		if (last_result == RESULT_LOCKED) {
			/* Acting on the locked pattern: unlock, then read back. */
			local_unlock();
		}
		else {
			local_read();
		}
	}
	if (released && read_armed) {
		/* Released too early, treat it as a cancel. */
		read_armed = false;
		show_result();
	}

	/*
	 * BTN2 dismisses the latched result after a 1 s hold. It shows nothing
	 * while held: the LED is saying whether the pack is locked, and blinking
	 * white over that answer to report a button being pressed buried the one
	 * thing it is there for. Going dark at the 1 s mark is the confirmation.
	 */
	button_update(&btn_clear, &pressed, &released);
	if (pressed) {
		clear_armed = true;
	}
	if (clear_armed && btn_clear.state && (millis() - btn_clear.t_pressed) >= BTN_CLEAR_HOLD_MS) {
		clear_armed = false;
		last_result = RESULT_NONE;
		show_idle();
	}
	if (released) {
		clear_armed = false;
	}
}

/** Nothing to refresh: the LED holds the last result, or stays dark. */
void update_status() {
	if (last_result != RESULT_NONE || read_armed || led_holding()) {
		return;
	}

	show_idle();
}

void setup() {
	Serial.begin (9600);
    // One-wire
	pinMode(ENABLE_PIN, OUTPUT);
	//pinMode(2, OUTPUT);

	// Pack voltage is measured against the internal 1.1V bandgap, not AVCC.
	// AREF (U1 pin 18) is left unconnected on the board, so this is safe.
	analogReference(INTERNAL);
	// The conversions right after switching the reference are not valid.
	delay(10);
	analogRead(VBAT_ADC_PIN);
	analogRead(VBAT_ADC_PIN);

	// Status LED and buttons
	status_led.begin();
	status_led.clear();
	status_led.show();

	button_init(&btn_read, BTN_READ_PIN);
	button_init(&btn_clear, BTN_CLEAR_PIN);

	led_selftest();
	show_idle();
}

void send_usb(byte *rsp, byte rsp_len) {
    for (int i=0; i < rsp_len; i++) {
        Serial.write(rsp[i]);
    }
}

void read_usb() {
    if (Serial.available() >= 4) {
        byte start = Serial.read();
        byte cmd;
        byte len;
        byte data[255];
        byte rsp[255];
        byte rsp_len;

        if (start == 0x01) {
            len = Serial.read();
            rsp_len = Serial.read();
            cmd = Serial.read();
            if (len > 0){
                for (int i = 0; i < len; i++) {
                    while (Serial.available() < 1);
                    data[i] = Serial.read();
                }
            }
        }
        else {
            return;
        }
        /* Set RTS */
    	digitalWrite(ENABLE_PIN, HIGH);
	    delay(400);

        switch(cmd) {
            case 0x01:
                rsp[0] = 0x01;
                rsp[2] = ARDUINO_OBI_VERSION_MAJOR;
                rsp[3] = ARDUINO_OBI_VERSION_MINOR;
                rsp[4] = ARDUINO_OBI_VERSION_PATCH;
                break;
            case 0x02: {
                /* Pack voltage measured on BAT_DIV, in millivolts (little endian). */
                float volts = read_pack_voltage();
                uint32_t mv = (volts > 0.0f) ? (uint32_t)(volts * 1000.0f) : 0;
                if (mv > 0xFFFE) {
                    mv = 0xFFFE;
                }
                rsp[2] = mv & 0xFF;
                rsp[3] = (mv >> 8) & 0xFF;
                break;
            }
            case 0x31:
                makita.reset();
                delayMicroseconds(400);
                makita.write(0xcc,0);
                delayMicroseconds(90);
                makita.write(0x99,0);
                delay(400);
                makita.reset();
                delayMicroseconds(400);
                makita.write(0x31,0);
                delayMicroseconds(90);
                rsp[3] = makita.read();
                delayMicroseconds(90);
                rsp[2] = makita.read();
                delayMicroseconds(90);
                break;
            case 0x32:
                makita.reset();
                delayMicroseconds(400);
                makita.write(0xcc,0);
                delayMicroseconds(90);
                makita.write(0x99,0);
                delay(400);
                makita.reset();
                delayMicroseconds(400);
                makita.write(0x32,0);
                delayMicroseconds(90);
                rsp[3] = makita.read();
                delayMicroseconds(90);
                rsp[2] = makita.read();
                delayMicroseconds(90);
                break;
            case 0x33:
                cmd_and_read_33(data, len, &rsp[2], rsp_len);
                break;
            case 0xCC:
                cmd_and_read_cc(data, len, &rsp[2], rsp_len);
                break;
            case 0x36: {
                /* F0513 cell voltages (five u16 LE in rsp[2..11]), read
                 * atomically in this one EN session. F0513 has no pack-voltage
                 * register: the pack voltage is the sum of cell registers
                 * 0x31..0x35, and those only answer after the bus is primed with
                 * a full basic transaction, with the first read or two after the
                 * switch to the CC path missing. So prime twice (power-cycling
                 * between) and read each register three times, keeping the last.
                 * Ported from the D1L firmware's f0513_read_all, where this was
                 * proven. The per-command path (case 0xCC) cannot do it: prime
                 * and reads must share one powered session, and each USB command
                 * is its own session. */
                static byte F0513_BASIC[2] = {0xAA, 0x00};
                byte warm[40];
                for (uint8_t i = 0; i < 10; i++) rsp[2 + i] = 0;

                for (uint8_t attempt = 0; attempt < 5; attempt++) {
                    if (attempt) {
                        digitalWrite(ENABLE_PIN, LOW);  delay(30);
                        digitalWrite(ENABLE_PIN, HIGH); delay(400);
                    }
                    cmd_and_read_33(F0513_BASIC, 2, warm, 32);
                    digitalWrite(ENABLE_PIN, LOW);  delay(30);
                    digitalWrite(ENABLE_PIN, HIGH); delay(400);
                    cmd_and_read_33(F0513_BASIC, 2, warm, 32);

                    uint16_t sum = 0;
                    uint8_t got = 0;
                    for (uint8_t i = 0; i < 5; i++) {
                        byte rc[1] = { (byte)(0x31 + i) };
                        byte reg[2] = { 0xFF, 0xFF };
                        cmd_and_read_cc(rc, 1, reg, 2);   // discard
                        cmd_and_read_cc(rc, 1, reg, 2);   // discard
                        cmd_and_read_cc(rc, 1, reg, 2);   // keep
                        rsp[2 + 2 * i] = reg[0];
                        rsp[3 + 2 * i] = reg[1];
                        uint16_t cv = (uint16_t)reg[0] | ((uint16_t)reg[1] << 8);
                        if (cv >= 100 && cv <= 5000) { sum += cv; got++; }
                    }
                    uint16_t c1 = (uint16_t)rsp[2] | ((uint16_t)rsp[3] << 8);
                    if (c1 >= 100 && c1 <= 5000 && got >= 4 && sum >= 3000 && sum <= 30000) {
                        break;   // good read; rsp[2..11] holds the five cells
                    }
                }
                break;
            }
            default:
                rsp_len = 0;
                break;
        }
        rsp[0] = cmd;
        rsp[1] = rsp_len;
        send_usb(rsp, rsp_len + 2);

        digitalWrite(ENABLE_PIN, LOW);
    }
}

void loop() {
    read_usb();
    handle_buttons();
    update_status();
    led_update();
}

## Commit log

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2026-08-18 Replace the Python application with a browser app
    The PC side is now a static Web Serial app under web/, so customers open a
    page instead of downloading an executable: no PyInstaller build, no antivirus
    false positives, no macOS notarisation, and an update reaches everyone at once.
    It installs as a PWA where the browser offers that, and ports authorised once
    reconnect silently on later visits.
    The protocol handling is a direct port of makita_lxt.py. Offsets shift by two
    because the transport strips the response header the Python code still carried,
    so the port was checked field by field against the original on random data
    before the Python was removed.
    Deploys to powerdiag.jp/obi: every pa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
2026-08-18 Drop the PyInstaller workflows
    They package the Python application that the browser app replaced, so they
    have been failing on every push since it was removed. The firmware workflow
    stays: it builds the Arduino and ESP32-C3 images on release.
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2026-08-18 Open on a landing screen and fit the dashboard on one screen
    Before a board is connected the page is the product name and a single
    button, so there is nothing to read and nothing to get wrong. Connecting
    swaps in the dashboard, whose header carries the name, the port and a
    disconnect that returns to the landing screen.
    The dashboard is now a viewport-height flex column: the page itself never
    scrolls and only a card scrolls internally if its contents overflow. Narrow
    or short viewports fall back to ordinary scrolling, where columns that thin
    would be worse than a scrollbar.
    User-facing strings no longer name another manufacturer; the protocol
    comments in the source still do, since that is w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
2026-08-18 Write down how the web app is served
    Both the origin and Cloudflare have to be told not to cache it, and the
    manifest needs a MIME type nginx does not ship with — a missing one leaves
    the page working while the app silently refuses to install.
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2026-08-18 Take the shared visual language from powerdiag-ui
    The styling was never OBI-specific, and the next tools would each have grown
    their own dialect of it. It now lives in PowerDiag/powerdiag-ui and is
    vendored here, leaving this repo with only what belongs to this tool: the
    connect screen and a few layout nudges, 11.2 KB down to 1.3 KB.
    Vendored rather than linked from a shared URL so the tool stays self-contained,
    works offline and on localhost, and cannot be broken by an edit elsewhere.
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2026-08-18 Wait out the board reset, and rearrange around the readout
    Opening the port toggles DTR, which on a Nano is coupled to RESET: the board
    reboots as we connect and the bootloader swallows whatever is written next,
    which shows up as every command timing out with no reply at all. Drive the
    control lines explicitly, then give the board two seconds before talking to it.
    The pack voltage moves into the card it summarises, which drops a whole row
    from the layout, and the lock badge moves next to the identity heading. The
    log now starts open with Clear and Export beside it, so a customer can hand
    support a file instead of a screenshot.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
2026-08-18 Identify the board before reporting a connection
    Any CH340 on the machine appears in the port picker, and picking the wrong
    one connected happily and then failed every command with a bare timeout. The
    version command now runs as the last step of connecting: no answer means the
    port is closed again and the user is told to pick another one, rather than
    being left on a dashboard wired to nothing.
    Every reply is also checked against the two header bytes the firmware echoes
    back, so a foreign device that happens to put the right number of bytes on
    the wire is rejected instead of parsed.
    The blanket two-second wait added for the reset theory is gone: the version
    probe already retries through a b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
2026-08-18 Fix the unterminated string that stopped the app loading
    The log export line ended up with real newlines inside its string literals
    instead of escapes, which is a syntax error, so app.js never ran: the language
    picker had no options and the connect button did nothing. Neither symptom had
    anything to do with the select styling I spent two rounds changing.
2026-08-18 Always close a port a connection failed on
    A failed connect left the port open while the UI went back to the landing
    screen, so the next attempt was refused with "the port is already open" and
    the user had no way forward but a reload. Two holes fed it: close() released
    a reader that still had a pending read, which throws and skipped the actual
    close, and only the version probe closed on failure, not the paths around it.
    close() now cancels, waits for the read loop, then releases, and reports a
    close that fails instead of swallowing it. connect() closes on any failure
    after the port is open, and open() recovers from a port an earlier attempt
    left behind rather than making the user replug the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
2026-08-18 Hand the port back, and name who is holding it
    A reload or a closed tab is not a process exit, so the port stayed claimed
    for the next window; release it on pagehide. And when the device is held by
    something outside this page — another tab running the tool, a serial monitor
    left open — say that, instead of reporting a bare open failure the user
    cannot act on.
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2026-08-18 Speak Traditional Chinese, Korean, Vietnamese and Thai
    The traffic has a small international tail behind Japan — Vietnam, Taiwan,
    Korea, Thailand — and English is a poor second language for a tool someone
    uses with a pack in their other hand. Each gets a typeface ahead of system-ui
    for the same reason Japanese does, and Taiwan gets traditional characters
    rather than the simplified set.
    These four are unverified: written carefully but by no native speaker, and
    the clear-errors confirmation in particular warns about something
    irreversible. Have that line read before treating any of them as finished.
    A script checks every language defines every string, since a forgotten key
    falls back to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
2026-08-18 Group the actions and let the readings be copied
    Clear errors sat directly beside the LED test, one irreversible and one
    harmless, in a flat row of equals. The groups now carry labels and the
    destructive one carries it in red.
    Copy puts the whole reading on the clipboard as text. A customer pasting a
    reading into a message gives searchable, quotable values; a screenshot of the
    same reading gives neither. Both ideas are upstream OBI-1's, and both were
    right.
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2026-08-19 Show a progress bar while the tool is working
    Connecting runs a port open, a settle and up to five version probes, which is
    several seconds during which a line of small text was the only sign anything
    was happening. The bar is driven by the same guard that disables the buttons,
    so it covers reads as well and cannot be left running after a failure.
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2026-08-19 Take the Traditional Chinese review
    A reviewer closer to the audience than I am: pack voltage reads as 電池組電壓
    rather than the colloquial 整包電壓, and instrument panels say 讀值 where I
    had 讀數. Simplified follows so the two do not drift into different words for
    the same thing.
    Three suggestions are not taken. 端子電壓 was read as 每子 and proposed as
    每節電壓, which is per-cell — a different measurement, shown in the tiles
    right above it, and the two sit side by side precisely to be compared.
    電池訊息 holds a raw 32-byte frame, so 訊息 is what it is; 資訊 would promise
    something processed and repeat the section heading. And the clear button
    releases th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
2026-08-19 Name both voltages by their source, and take the Korean review
    The measured figure is not a terminal voltage: it is the pack voltage, read
    by the board instead of reported by the BMS. Same quantity, two sources,
    which is the whole reason the two sit side by side — so both labels now say
    which source they come from, in every language.
    The Korean review lands on naturalness: 기능 테스트, 측정값 복사, 배터리 팩
    전압, 측정값 over 실측, 연결 안 됨 for a status strip, and a rephrased charge
    count footnote. Not taken: 오류 해제 releases the error flags in the BMS
    rather than deleting a log, and 배터리 메시지 holds a raw 32-byte frame, so
    메시지 is what it is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
2026-08-19 Take the Vietnamese and Thai reviews, and fix the label they all tripped on
    Both reviews land on the same kind of thing: the borrowed word "pack" reads
    as unfinished in either language, and a measured value is named as such
    rather than described. Thai is taken in full; Vietnamese keeps "cell", which
    is what the trade uses there.
    Three of four reviewers flagged the battery message field independently, and
    they were right for a reason none of them could see: it holds a raw 32-byte
    frame, so "message" was a bad name in English before it was a bad translation
    in anything else. Every language now says raw data.
    The reported gaps inside Vietnamese words are not an encoding fault — the
    strings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
2026-08-19 Soften the Japanese error wording
    接点 is the trade term and not wrong, but it reads hard in an interface and
    means little to someone who is not an electronics repairer. 端子の接触状態
    keeps what the message is actually about — this error means bytes came back
    all 0xFF, a floating bus, which is a pack seated but not making contact — so
    it stays distinguishable from the timeout, which is the pack not seated at
    all. The polite register is now consistent across the messages that ask the
    user to go and check something.
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2026-08-19 Frame the action row and align it right
    A bare row of buttons above the panels read as loose. Framed and pushed to
    the right, it ends where the cards end and sits as its own band.
2026-08-19 Sharpen the Chinese tagline
    "就能" softened the one thing the line exists to say. The Japanese master
    reads "with only a browser", meaning nothing to install, and 即可 carries that
    where 就能 merely allows it. 轻松 was offered and left out: it is promotional
    register, and it sits three lines above 状态码 and 电芯压差.
    Vietnamese loses an exclamation mark the other six do not have — an inverted
    band is already the loudest thing on the page.
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2026-08-19 Fill the height with the log, and offer a way to ask for a language
    Nothing in the shell claimed the leftover height, so the column stopped at its
    natural size and left a gap above the status bar. The panels now take most of
    it and an open log takes the rest, growing with the window down to a floor
    that still shows a few exchanges; the log's own controls move right to line up
    with the toolbar. The app's fixed 22vh cap is gone, since it fought all of that.
    The landing screen also offers a way to ask for a missing language. It stays
    English in every language on purpose: the person who needs to read it is the
    one who cannot read the interface.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
2026-08-19 Ask before clearing errors in the tool's own dialog
    confirm() prefixes the question with "powerdiag.jp says", cannot be styled and
    looks like something the browser is asking rather than the tool. It is the
    most consequential question here — the operation clears the pack's error flags
    and on some batteries resets the charge count — and it looked like the least
    considered part of the interface.
    The native dialog carries the tool's frame and the red heading that names what
    the action does, while the browser still supplies the modal behaviour, the
    focus trap and Esc.
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2026-08-19 Offer to install the tool as an app
    The page already meets the install criteria, so Chromium has been offering it
    all along behind an address-bar icon nobody notices. Installed, it opens in
    its own window with its own shortcut and keeps working offline, while still
    running on the browser already on the machine — which is the reason this is a
    web app rather than something to download.
    The browser hands over the prompt rather than letting us raise one, so the
    button appears only once it has, and leaves once the app is installed.
2026-08-19 Say which of the three install states applies
    Install, installed, or cannot be installed here. The third can only be
    inferred — a browser that can install offers the prompt shortly after load,
    so silence past that means this one cannot — but saying it beats a button
    that would do nothing, or no answer at all for a customer wondering where the
    app went. The installed state opens the note explaining that a page cannot
    remove itself and where the control actually lives.
    The string checker that guards against the syntax error which once took the
    whole app down is now a real scan rather than a set of regexes, which had
    been reporting innocent lines: "//" appears inside 'edge://apps', and bla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
2026-08-19 Stop waiting on a network that is barely there
    Network-first had no bound on the wait. A dead connection fails at once and
    costs nothing, but a half-dead one — weak workshop Wi-Fi, a phone on one bar —
    can hang for half a minute, which is slower than being offline outright.
    After two and a half seconds the cached copy is served instead. The request
    carries on regardless, and whatever arrives late still refreshes the cache, so
    the delay is paid once rather than on every launch.
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2026-08-19 Write the manufacturing date the way the reader writes dates
    The pack sends year, month and day as three numbers; the reference code
    assembled them as DD/MM/YYYY and the port carried that over. Read in Japan
    that order is simply wrong, read in the United States it says month 25, and a
    pack built on 07/08 is genuinely ambiguous either way.
    The parts now survive as parts and Intl orders them for whoever is looking. A
    date the pack could not have — month 13, day 40 — keeps its raw figures
    instead: that reading is a symptom, and rolling it silently into a plausible
    date would hide the fault this tool exists to find. Gregorian is forced, since
    some locales would otherwise answer in another e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
2026-08-20 Take the cell count from the pack, not from an assumption
    Five cells was hardcoded in three places, which is right for an 18 V pack and
    wrong for a 14.4 V one — four cells on the same connector. The fifth slot came
    back empty, the spread was computed against it, and the tile went red: a
    healthy pack reported as having a dead cell, which is the worst kind of wrong
    for a tool someone trusts to tell them what to replace.
    The count is in the flags byte of the basic frame we already read, as the D1L
    firmware does it, and it notes why: the model name comes from a command faulty
    packs often refuse, while this byte arrives with the frame regardless. The
    offset is verified against the real BL1860B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
2026-08-27 ArduinoOBI: archive the upstream v0.2.1 firmware and the Nano flasher
    Keeps a board recoverable to stock without rebuilding an upstream
    checkout: to reproduce a bug against the original, to check whether some
    behaviour predates our changes, or to hand someone a board running the
    same code as the upstream project. The image reports 0.2.1, which is how
    you tell it apart from this repo's firmware at a glance.
    The hex is the unmodified upstream 1a24a38 nano build, and FLASH.md
    records its SHA256 so the provenance can be re-checked later.
    Flash-Nano.ps1 comes along because the hex is close to unusable without
    it: on the FTDI and CH340 Nano clones this project uses, auto-reset does
    not cooperate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
2026-08-31 Run the LED through red, green and blue at power-up
    It says the firmware started, which the old single blue flash also said, and
    it says all three channels of the WS2812 work, which nothing did. A dead
    channel otherwise surfaces much later as an idle colour that reads wrong —
    amber where it should be green — and that is a hard fault to notice at all,
    let alone track down.
    The idle voltage colour now comes up directly after, rather than waiting for
    the first loop.
    [main.cpp]
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2026-09-01 Stop the LED talking over its own answer
    BTN2 blinked white from the moment it was touched, painting over the lock
    state to report a button being pressed. The button now shows nothing while
    held and dismisses the result after 3 s; the LED going dark is the
    confirmation, and it is a better one than the blinking was.
    A failed read blinked magenta until the board was unplugged, because an
    expired hold only ended led_holding() and never touched the pixel — nothing
    that was not replaced by a later led_set() could stop. led_set_transient()
    closes that: the pattern says its piece and the LED goes dark. A failed read
    takes 3 s of it. The lock state is exempt and still waits indefinitely — it is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
    [POWERDIAG_OBI_CASE_1.f3d, POWERDIAG_OBI_CASE_1.stl, POWERDIAG_OBI_CASE_2.f3d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]
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2026-09-01 ArduinoOBI: shorten the failed-read blink and the BTN2 dismiss hold
    Both were longer than they needed to be in use. The magenta "no usable
    answer" blink now runs 2 s instead of 3, and BTN2 dismisses after a 1 s
    hold instead of 3 s.
    Shortening BTN2 costs nothing: it only clears the latched result and
    turns the LED off, and never writes to the battery, so the long hold was
    never a guard against anything. At 1 s it also matches BTN1, so both
    buttons are simply "hold for a second". The comment explaining the hold
    as deliberate-because-unlit went with it, since that reasoning no longer
    describes the value.
    Both READMEs documented the old 3 s figures in five places; updated so
    the docs and the f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
    [main.cpp]
2026-09-03 Flash the Nano from the browser
    A kit arrives as a bare board and a Nano the buyer solders on, so the first
    thing it needs is firmware — and until now that meant installing PlatformIO or
    the Arduino IDE first. An afternoon of setup stood between a finished solder
    joint and a working tool, for a step that is one command and thirty seconds.
    The bootloader is already on every Nano; the only thing missing was something
    to talk to it.
    stk500.js is that, written from AVR061 rather than ported from an existing
    flasher: sync, enter, load address, program page, leave, and every reply inside
    the same 0x14..0x10 envelope. It writes, then reads every page back and
    compares. Trusting the acknowledgeme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
2026-09-04 Move flashing out of the diagnostic app
    Flashing is not diagnostics. It happens once, on a board that does not work
    yet, and putting it on the connect screen of a tool people open to read a
    battery meant everyone met a button they would use at most one time. It gets
    its own page at powerdiag.jp/flash instead, reachable by typing the address —
    which is also the right amount of exposure for something that has never run
    against real hardware.
    The syntax check stays. This machine has no Node, so nothing local caught the
    one syntax error that took the whole app down; QuickJS parses the same files
    and now the gate exists whether or not a toolchain does.
    .gitattributes stays too: core.autocrlf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
2026-09-11 web: fix remote-dialog field padding and dashboard top scroll
    Two layout fixes:
    * The remote dialog's fields ran flush to the dialog edges. .dialog has
    padding:0 and each of .dialog-title/.dialog-body/.dialog-actions carries its
    own 20px, but .remote-form had none, so the channel select and PIN input sat
    outside the 20px column the body text lines up on. Pad the form to 20px and
    lift the actions footer out of it, so its strip still spans the full width.
    * The dashboard's voltage/identity cards grew their own scrollbars: the shared
    library gives .grid flex:2 and lets the cards scroll when the column squeezes
    them. Pin .grid to its natural height (scoped to the app-shell breakpoi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
2026-09-11 web: fix F0513 cell reads (0.00 V on every cell)
    readCellsF0513 did three things our own hardware testing had already shown are
    wrong for F0513, and every cell read 0.00 V because of them:
    - It sent CLEAR (F0 00) to "settle the bus". On F0513 that leaves the BMS in a
    state where the cell registers read back 0. Removed — this was the direct
    cause.
    - It read each 0x31..0x35 register once. Cold onto the CC register path the
    first read or two miss, so each register is now read three times and only
    the last kept (discard/discard/use).
    - It never primed the bus. A basic 0x33 AA 00 transaction now runs twice
    first, which settles the pack and also re-settles it after the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
2026-09-11 tools: stamp sw.js CACHE with the deploy commit (auto cache-bust)
    The service-worker CACHE name had to be bumped by hand whenever a web asset
    changed, and the one time it was forgotten a returning browser served an old
    lxt.js for a change that was correct end to end — the F0513 read went out over
    0x36 in the deployed file but the cached copy still sent the old CC 31..35, and
    it took a direct relay probe to see the browser wasn't sending 0x36 at all.
    stamp-version.py already runs before every deploy (it writes version.js from
    HEAD); now it also rewrites sw.js's CACHE to powerdiag-obi-<commit>. The commit
    changes every deploy, so the name changes, so the activate handler drops the
    old cache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
2026-09-17 Add opt-out checkbox to send readings to PowerDiag
    Adds a checkbox next to 'Read everything', checked by default, that
    POSTs each reading to https://api.powerdiag.jp/v1/obi/reading so we
    can see pack health trends and firmware compatibility across real
    devices. Unchecked, nothing is sent; the choice is remembered in
    localStorage. A failed upload only logs quietly and never disrupts
    the on-screen reading. Translated into all 7 UI languages.
    Backend endpoint lands in WanpengQian/powerdiag-api.
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2026-09-18 Support both firmwares: stock ArduinoOBI and PowerDiag 9.x
    The board runs one of two firmwares and the app had no way to tell them
    apart, so it sent this repo's extra commands at stock boards too. Stock
    answers nothing to 0x36, which surfaced as a 12s hang and a "check the
    battery" timeout on F0513 packs — with nothing wrong with the battery.
    Firmware now numbers itself 9.0.0. Upstream is at 0.x.x (stock ships
    0.2.1), so a major of 9 or above means this repo's build and nothing
    upstream can ever collide with it. The 0.3.x builds that predate the
    scheme count as stock and should be reflashed.
    The web app reads the version once on connect and picks the read path
    from it:
    - PowerDiag (9.x.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
    [main.cpp]
2026-09-18 Document where this firmware is built and released
    Maintenance moved onto the PowerDiag server: PlatformIO is installed
    there and the AVR toolchain fetched, so builds no longer depend on a
    Windows machine. Writes down the release path through the web flasher
    too — in particular that index.json's version is what the OBI app keys
    its read path off, and that bytes is the program size, not the file
    size.
2026-09-18 Show the build next to the app name
    The status bar already carried it, but that is at the bottom of the page
    and disappears the moment a dashboard replaces the landing screen — so
    someone asked "which version are you on?" had nowhere obvious to look.
    Same string, now also beside the name. Wraps to its own line rather than
    squeezing the name on narrow screens.
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
